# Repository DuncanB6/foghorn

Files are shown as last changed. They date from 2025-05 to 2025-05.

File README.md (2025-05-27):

# Foghorn

<p align="left">
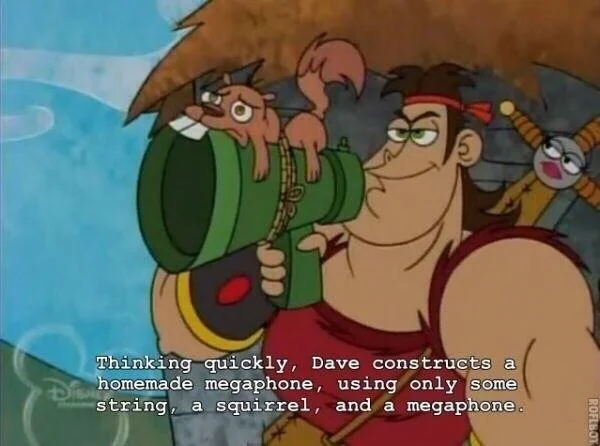
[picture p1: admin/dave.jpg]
  
</p>

A short range portable FM transmitter.

---

## Table of Contents

- [Overview](#overview)
- [Project Structure](#project-structure)
- [Hardware](#hardware)
- [Firmware](#firmware)

---

## Overview

This is an FM transmitter that a user can use to broadcast their voice or audio from an AUX port on the FM band at short ranges. As an audio source, it uses either an onboard microphone or the external AUX port. The user can transmit their voice much like a walkie talkie, and can play music if they want. The transmitter is tunable to any FM band frequency using buttons.

<p align="left">
  Foghorn Project Banner
</p>

The project was originally named Foghorn because I had imagined it as a megaphone. I though this would allow for some interesting antenna design, and also be funny. However, after realizing that the antenna didn't matter too much, I fell to the tempation of making it smaller, and so a radio design was born.

Foghorn is built on a series of development boards. An ESP32 board provides the computing, which is connected to an electret microphone, LCD screen, FM transmitter, and the buttons and switches needed to run the device. The whole thing is powered by a lithium ion battery, rechargable using a battery board. Firmware is written using ESP-IDF.

<p align="left">
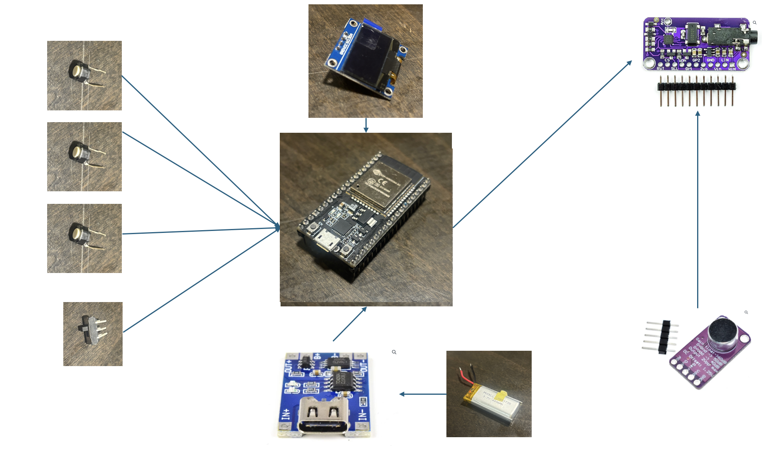
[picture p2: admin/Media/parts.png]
  
</p>

---

## Project Structure

This repository contains everything involved with this project. Some of the main folders are as follows.

- admin: Administrative stuff, such as a log, BoM, pictures, etc.
- arduino: Code used with an Arduino Uno to test out the FM transmitter.
- main: Firmware for the ESP32, used in the final version.
- stls: STL files used for mechanical parts (3D printed).

## Hardware

### Electronics

This device consists of several development boards and other odd electronics. A sketch of the system is shown below.

<p align="left">
  Foghorn Project Banner
</p>

All parts are wired together using 26AWG wire and heat shrink.

#### Battery Board (BB)

The battery board is a board that allows for the charging of my lithium ion battery. I don't know what kind of battery it is (3.7V 400mAh) cause I just had it lying around. The battery board provides 3.3V and ground terminals for the entire system. The BB can be found here: https://www.universal-solder.ca/product/3-7v-lithium-charger-usb-c-1a-charge-3a-output-protection-usb-c/

#### FM transmitter

The FM transmitter is connected to the ESP32 via I2C and the microphone using a single line. It transmits at a short range on the FM band. An approximately 20cm wire antenna extends out from this board. You can find it here: https://www.universal-solder.ca/product/si4713-fm-stereo-transmitter-module-with-rds/

#### Microphone

The microphone is an electret microphone board with adjustable gain. I have it set to the lowest setting (40dB) right now, which works fine. Its analog output is connected to the analog input of the FM transmitter. Find it here: https://www.universal-solder.ca/product/hifi-microphone-module-with-max9814-amplifier/

#### LCD

THe LCD is a 4056 powered 128x64 I2C LCD. It is connected on the I2C lines to the ESP32 board. This provides a 0.97" monochrome display to display the frequency. I don't have a link cause it was just lying around.

#### ESP32

The ESP is connected to all of the peripherals. Also just had this lying around, so no link for you. It's a pretty standard ESP dev board though.

#### IO

There are 3 buttons and one switch. The switch is on the 3.3V line between the battery board and the rest of the system. THe push to talk button is on the analog audio line between the FM transmitter and the microphone. The up and down frequency buttons are connected to two ESP32 GPIO inputs.

### Mechanical

Most parts are 3D printed using my Prusa Mk3S+ printer. The case is made from brown ASA, the buttons from green ABS, and the antenna from flexible TPU. Parts are fastened together using M2.5 screws and heat inserts. The buttons and switch are glued in.

<p align="left">
  Foghorn Project Banner
</p>

Parts were designed in Onshape. Note that M2.5 screws was a bad choice, since these take up more space than necessary and don't fit in the microphone or LCD mounting holes (although for the LCD I made it happen).

<p align="left">
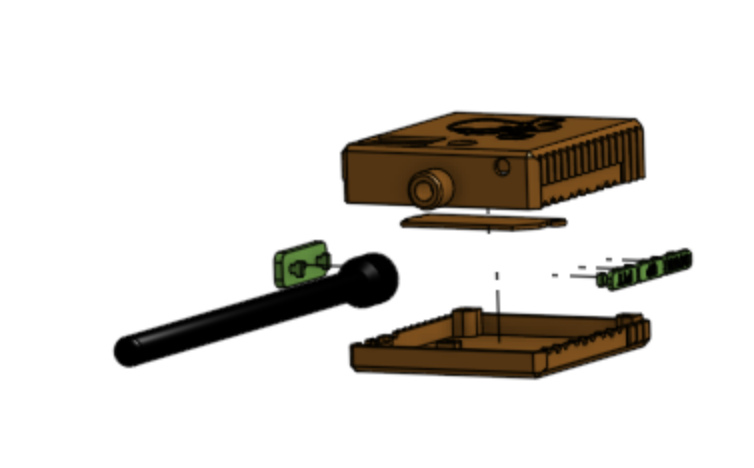
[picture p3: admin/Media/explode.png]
  
</p>

## Firmware

The current firmware is in the "main" folder. This firmware is responsible for interacting with all of the peripherals. All processing happens in a single task. The initialization flow is as follows.

1. Initialize I2C (LCD and FM transmitter)
2. Initialize GPIO
3. Initialize LCD
4. Initialize FM transmitter (begin transmitting)
5. Display initial frequency on LCD

Once initialization is complete, we enter the main loop. If the frequency up button is pressed, the frequency is increased by 0.2 MHz and the FM transmitter is tuned to match. The new frequency is displayed. I'll let your imagination fill in what happens when the frequency down button is pressed.

In the background, the LCD screen is constantly updated. Otherwise, the only task the ESP32 performs is monitoring the frequency up and frequency down buttons.

Code is fairly sparsly commented, and has undergone some pretty major shifts, so I make no claims to this being particularily robust or clean work.

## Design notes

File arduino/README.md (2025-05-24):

# foghorn-arduino
Arduino firmware for testing and development towards the Foghorn project

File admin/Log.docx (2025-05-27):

Foghorn Log:

Apr 4:

- Did some initial research, I have some components that seem promising
  - I need to finish component selection before I can order
- Do I need an amplifier?
  - If there are relatively easy, cheap options, I’ll do this
- I want input from either ESP32 or microphone, is it easier to do this before or after the DAC?
  - How does I2S work? Can I share lines, and will having 3 devices on the line cause problems for the unused device?
  - It seems like I probably want to do this before DAC if possible, to avoid issues with analog levels/amplification

Apr 7:

- I ended up buying some parts, the Adafruit FM transmitter, a DAC, and a microphone
  - ESP32 can handle I2S audio, but I can’t share a line because it would have to be master and slave at once (only one channel)
- No amplifier at the moment, I may have to look at amplifying options later, but that will be a stretch goal
- Going to get through finals and wait for parts to arrive, then we roll!

May 8:

- Parts are all here, and I’m free from school, time to get to work
- First step is reviewing hardware
  - I’ll try out just the FM transmitter first with an audio source
- Oopsie, first hardware oversight, I’ll need an aux cable to test this out
  - Will buy
- Initial setup:
  - Arduino UNO on breadboard
  - Wires soldered to relevant FM transmitter pins
  - Phone connected to aux input
- I have all hardware set up
- When running the example code, I seem to have an issue with the I2C connecting
  - Make sure connections are all good
    - Seems all good, but reset and ground are connected when powered, why?
  - Try authentic Arduino
    - Same result
  - Investigate voltages
    - I2C pins seem to be high
    - Reset is 3.3V, why?
  - Very strange that reset (pin 12) and GND are both connected and separated by 3.3V when the thing’s running
  - Review code
    - Seems like a normal connection, I might revisit this, but ok for now
  - Pullup resistors
    - Added 10k resistors, no luck
- Fixed!
  - Connecting the reset pin and ground seems to solve the problem, I’ll have to figure out a software solution to this
    - Added a manual reset with the reset pin
- Radio works well
  - Very clear
  - 10m range with no problems
  - 50m absolute range
- May play with antenna a bit
- Done for today, next step is to integrate more components!

May 10:

- Damn it, I drained a pair of AAAs by leaving the radio receiver on
  - Gonna make it a habit to take batteries out
- Next steps:
  - Test to see if the device works without pullup resistors
  - Figure out why it seems to work intermittently
  - Figure out how it works
  - Set up github project (?)
  - Begin porting to ESP32
- Works fine without pullups, although same issues with inconsistency
- Ok, I have ideas for a solution to fix consistency, but first let’s set up the git so I don’t mess this up
- The antenna capacitance could be an issue
  - I’ve shortened the antenna to about a foot, still same behaviour
  - Tried a few different frequencies, no change
  - Tried adding a delay after reset, this may have improved things slightly, but problem is not solved
  - Aha, adding this delay after the begin function (I2C init?) solves the problem
    - This was because of a ramp-up time that the crystal oscillator needs, which explains the close but not quite freqs I was getting sometimes

May 11:

- Focus for today is transferring to ESP32 hardware
- First step is to see if I can get it working using raw I2C commands, that way I can transfer easily without worrying as much about hardware
  - Will start this by reading the FM transmitter programming datasheet
- Looks like I might not need a DAC after all, it has digital audio input options including I2S
- Wait a second, what if I can just use the existing library?
  - I have decided to not do that
  - Although possible, it’s going to be tricky to port, and I’d rather deal with low level I2C command sending trouble than library trouble
- Switched to using VS Code and PlatformIO for this
  - Open serial monitor using command palette
- Yay, got it set up so that I can power it up using a few of my own commands (but mostly still library)
- I think this serves as a good proof of concept, I’m going to make the leap to ESP32
- First step is setting up the build environment, this will require a lot of transfer from the old code
- Build env set up
- Added I2C and GPIO init functions
- Next step is to begin the long and arduous process of initializing using I2C

May 13:

- I’ve just tried getting the part number off the FM transmitter with I2C and Arduino, this will be a good first step for ESP32
- Now to do the hardware wiring
- No FUCKING way it worked first try
- Now to reorganize/format my code so that it’s a bit cleaner before moving forwards
- Alright, on to the grindy part of adding all the commands I want
- We’re balling
  - FM transmission working from ESP32
- Now just gonna chuck it into a task

May 14:

- Sike, I2C error
  - May be hardware, will investigate
  - Fixed, was just a mistake with passing i2c handle
- Decided not to put init in task for now, since it only needs to run once
- Going to look into I2S, ideally I’d like to try I2S transmission from ESP to FM without involving mic first
- Sike, the mic is not I2S, that’s actually nice
- Means I’ll do ADC on ESP32, but always output I2S
- Sike, I can’t use digital with the FM radio, must transmit to DAC first
  - Just took me quite a while to figure out stuff I already knew a month ago
- Note that setting the mute pin high on the DAC mutes the output, this could be a good way to implement push-to-talk
- Just wired up DAC, now computer doesn’t recognize ESP, very concerning, will debug
  - Cause by a solder bridge
  - Yikes, looks like this put the esp into bootloader mode
  - Hmm, seems like the issue is that my new firmware was so aids that it bricked the MCU
- Sequence to unbrick:
  - While holding boot, press reset (GPIO9 floating)
  - Flash the code (will fail)
  - While holding boot, press reset (GPIO9 pulled to high)
  - Flash code
- So it seems pins 12 and 13 are used for the JTAG interface, this is almost certainly causing the issue
- Will resolder to pins 19, 20
- Ok, it kinda works now, but there’s some kinda issue that causes distortion
  - In any case, enough for today

May 15:

- I’m not going to bother fixing the I2S sine wave, since it way be a problem with the wave, not the I2S
- Instead, let’s get the microphone set up
  - After soldering microphone, I get an issue with too much power, gonna try restarting mac
- Beginning to think I’ve fried my esp32, I’m gonna start removing connections, if it is broken I’ll have to do this anyways
- All desoldered and same result
  - I hate this board
- Since board is broken, I need to reevaluate my hardware
- Ok I’m gonna pivot and use ESP32 with SDD1306 LCD display
  - I have two ESP32s
- Gonna put everything together on a breadboard
- Soldering time

May 16:

- Got the FM working and maybe the DAC, but gonna try mic first
- First I’ll connect and just read a stream to see what’s up
  - Mic seems to be reactive at least, now to convert to I2S
- Not sure what the best way of passing data is
- Set up a queue, but should get DAQ done with a timer for consistent sampling freq

May 19:

- First step is to get acquisition on a timer for consistency
- Then I’ll work on using that data (converting and sending on I2S)
- Ok, DAQ is on timer, using 44.1kHz for now, may change
- Now to set up my receiving task that sends to I2S
  - Data consumption done, now just need to send
- I get audio from the DAC, but it’s incomprehensible at low sample rates and my queue overflows at high sample rates
- I have a feeling high data rates are gonna pose some issues

May 20:

- Round two!
  - Got to figure out high freq sampling
  - First, let’s determine exactly who is blocking
- Looks like I can’t sample the ADC in the kHz range (or at least 16kHz)
- What if I connected the mic’s analog out directly to the FM transmitter?
  - Would mean I’d need to control the FM transmitter to control output
  - May run into the same problem later with I2S comms
    - But Bluetooth (the only thing that needs I2S) is a stretch goal anyways
- Fuck yeah baby she’s going!
- Ok so massive simplification
  - DAC is completely dropped
  - Mic output goes directly into FM
- Next steps:
  - Figure out how to turn FM on and off
- I think it’s acceptable if the mic has a button on the output line
  - Means the radio will hear silence even when voice is not being transmitted
  - But this is ok, simplifies things, and may even be a feature
- Wow, now I just need to sort out tuning and the power cycle!
  - Huge progress by cutting fat
- I2S should be kept in, as it could be implemented later
  - Will be saved in a commit
  - Will have to remember to wire it up for I2S (or Bluetooth output of some sort)
- I should try the other gain settings on the mic before wiring everything up
  - Tried high gain, I prefer just regular, it sounds fine
- Got FM tuning IO going, as well as push to talk
- Now for the most feared part, the screen
- I likely have the following screen:
  - SSD1306 controller
  - 128x64 size screen
- Ok, after a lot of poking around, I have a demo going
- Now I just need to integrate this into my main project
- Raaahhhhhhhhhhhhh
  - Got the frequency display working
  - May see if I can get an indicator going for the voice
  - That may be tricky given the way I’ve implemented it (button on line)
- Should add some safeties for the FM limits
- Wow, I think I’m pretty much done!
- Should test plugging a phone on while the mic is running
  - No problem, phone audio overwhelms mic audio
- Let’s check out how the battery board needs to work, then I’ll start CAD!
  - Seems it doesn’t really talk with smart chargers like my laptop or its charger
  - Does seem to work otherwise
- CAD time!
- I’m gonna need some kinda glue to hold all my parts in place

May 21:

- First test print done, gonna disassemble board to test parts
- Rev two is printing now, made some good changes, this rev is technically fully functional
  - Although it probably will have mistakes
  - And is unpolished
- Print is 80% done, seems something got messed up on 2 layers
  - Maybe filament got stuck, not sure
  - Should still be enough to try out the next rev

May 22:

- After some adjustments, I’m now printing what I hope to be the final rev
- Also have ordered some stuff for assembly, which I’ll likely do Saturday
- All looking good, now we just wait for prints and parts
- Docs are gonna be a bit of a pain, but I can do that in my own time later

May 23:

- Only part left to print in antenna
- TPU is annoying, the height of it causes a lot of wobbling, and supports are unusable
- Gonna try printing real slow
- All parts printed, they look pretty good
- Now to wait for parts to arrive (today) and we can start the final build

May 25:

- I’ve made it most of the way through the build
- Unfortunately, I need to order parts
- The LCD screen seems to be broken, which is likely given what I was doing to it, and I’ve run out of leaded solder (and soon unleaded)
- New parts are ordered, but build is on hold till they arrive
- Final steps:
  - Replace LCD
  - Test LCD
  - Glue in buttons and switch
  - Wire switch
  - Wire button positive leads
  - Test system
  - Done!

May 26:

- Just replaced the LCD but am having the same issue
- Will look into a few things, but if this thing came broken or was immediately broken by soldering I’ll piss myself
- To check:
  - Getting 3V3 power?
    - Yes, but maybe adding a cap would help?
  - Pins are correct (in firmware)?
    - Fuuuuuuuuuuuuck
- Ok so I really should have checked that before getting a new screen, old one is likely not broken
  - Damn it
- New screen is not quite the right size, but it’s close enough and also blue so I’ll keep it
  - Also was planning on gluing the screen anyways cause the mounts are bad
  - The holes are 2mm (my screws are 2.5mm)
- All installed, and to nobody’s surprise it works
- Glued parts, just waiting for them to dry now
- Call me god king Duncan

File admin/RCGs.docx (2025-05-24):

Description:

The Foghorn should be a handheld electronic device that receives a user’s voice using a microphone and broadcasts it on an FM band. It should be tunable so that the user can choose the frequency of broadcast.

The user should see the current frequency displayed on the device and be able to adjust it with physical controls. The users voice should only be broadcast when the user applies a physical control (e.g. button, trigger).

The device should be able to broadcast a signal such that a nearby FM radio can receive that signal. The FM radio user should be able to discern what the Foghorn user is saying.

The device should be battery powered and rechargeable. It should be able to be switched off when not in use. The entire package should fit within a microwave.

Use:

The user turns on the device using a switch. After a short boot time, the device is ready for use. The user can adjust buttons to adjust the frequency, which is displayed on a small screen on the side of the device. Next, the user can depress a trigger or button and begin speaking. When the button is released, live transmission stops. The user can switch off the device using the power switch.

Requirements:

- Users voice must be comprehensible on an FM radio up to 10 meters.
  - Device will be used 10 meters from a radio. FM radio input will be recorded.
- Output frequency must be able to consistently target a single FM frequency within 0.2MHz.
  - 5 different frequencies will be checked on the FM band. Device should transmit at the target frequency but be inaudible at adjacent (+/- 0.2MHz) frequencies.
- Battery should last for up to 30 minutes of continuous use.
  - Device will be powered on and set to broadcast at medium power for 30 minutes.
- User must be able to tune frequency across the FM band.
  - Check minimum and maximum FM frequencies using an FM radio.

Constraints:

- Must fit within a handheld (toaster or smaller) package.
- Must transmit quietly enough to avoid annoying or alerting the public in a radius larger than 100 meters.
- Total parts cost must not exceed $300.

Goals:

- Allow audio input to be played from device using a wireless connection with a phone.
- Allow for tunable power for longer or shorter ranges.

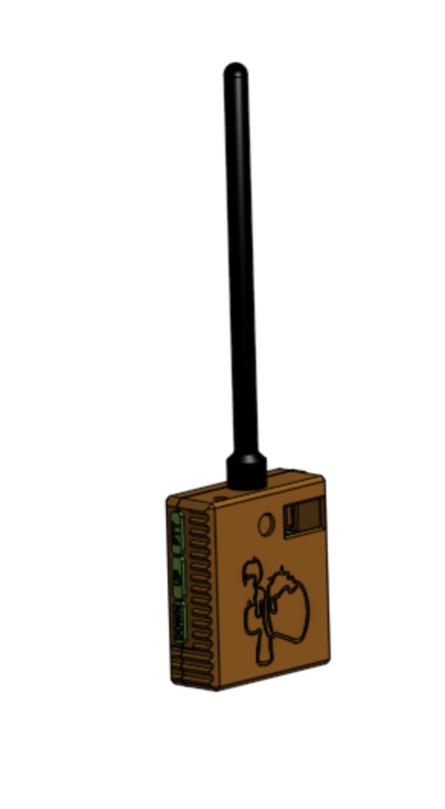
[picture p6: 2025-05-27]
admin/Media/complete.png

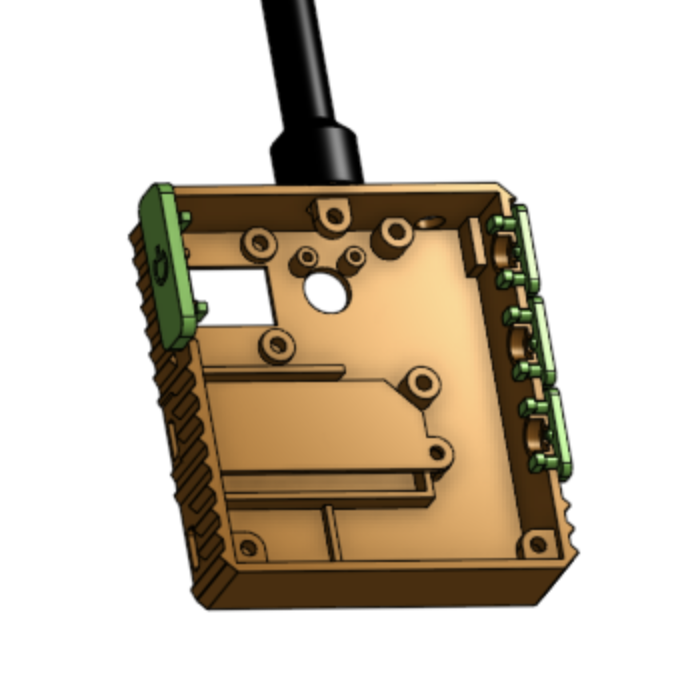
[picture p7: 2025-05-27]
admin/Media/case.png

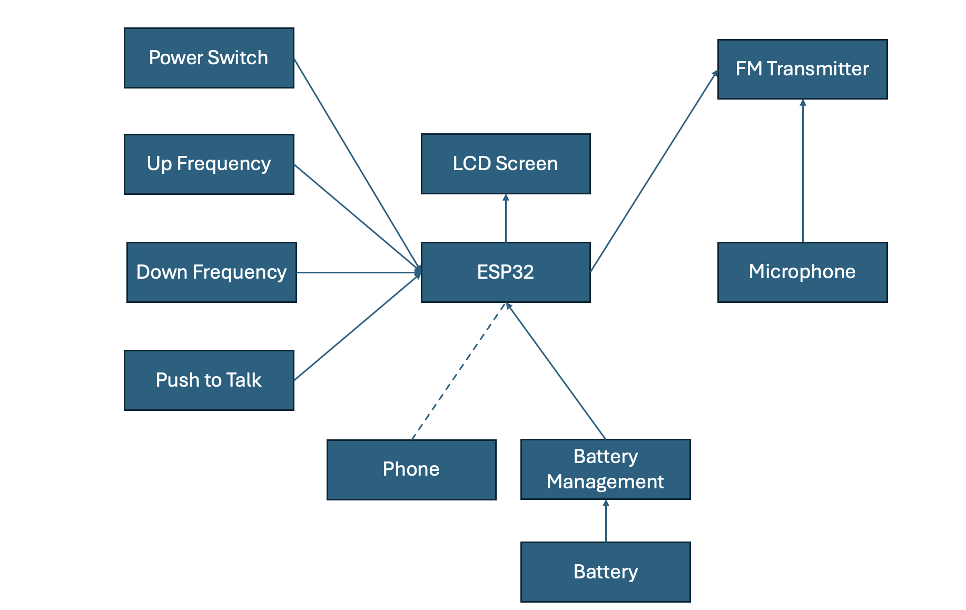
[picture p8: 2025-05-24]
admin/Media/block.png

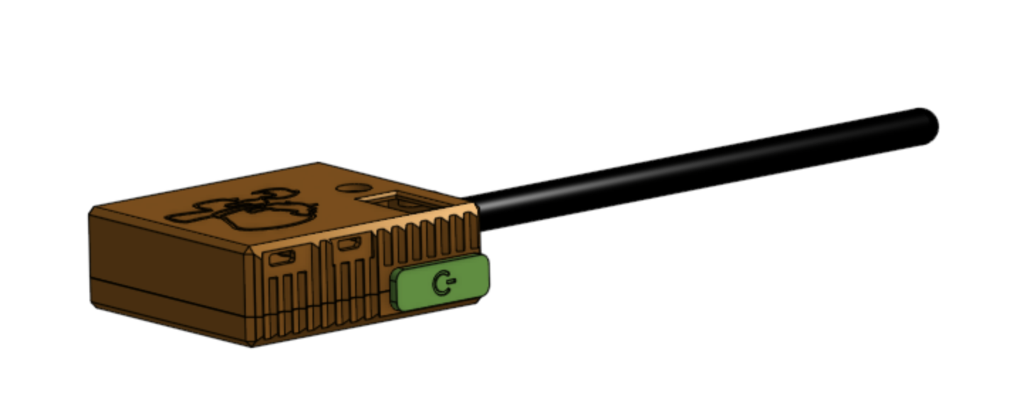
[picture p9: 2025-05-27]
admin/Media/side.png

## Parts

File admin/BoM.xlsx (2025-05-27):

Item | Cost (CAD) | Link | Running Total: | 127.0302
Adafruit FM Transmitter | 13.9 | https://www.adafruit.com/product/1958
Microphone Module | 3.95 | https://www.adafruit.com/product/1713
Battery Charger | 1.49 | https://www.universal-solder.ca/product/3-7v-lithium-charger-usb-c-1a-charge-3a-output-protection-usb-c/
Universal Solder Shipping | 4.9 | NA
Universal Solder Tax | 2.32 | NA
Adafruit I2S DAC | 10.147 | https://www.adafruit.com/product/3678
Adafruit Shipping | 26.1632 | NA
ESP32 C6 | 31.35 | https://www.amazon.ca/ESP32-C6-Microcontroller-1-47inch-Colorful-Applications/dp/B0DHVQYFGM
AUX Cable | 12 | NA
Wire, Glue, and Screws (Amazon) | 0.37 | NA
Replacement Screen and Solder | 20.44 | NA

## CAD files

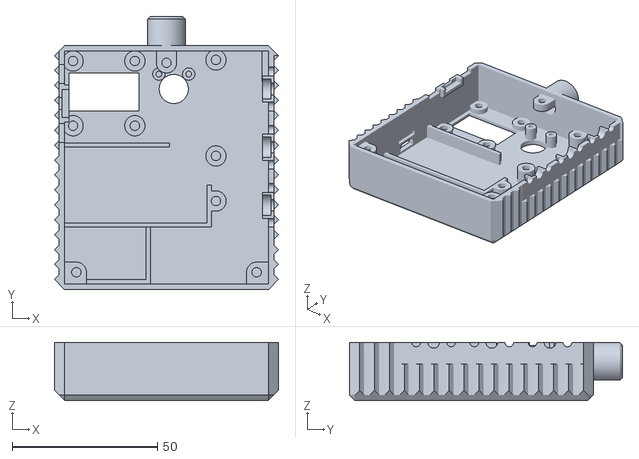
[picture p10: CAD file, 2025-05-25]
stls/Front - Part 1.stl
77.0 x 94.0 x 20.0

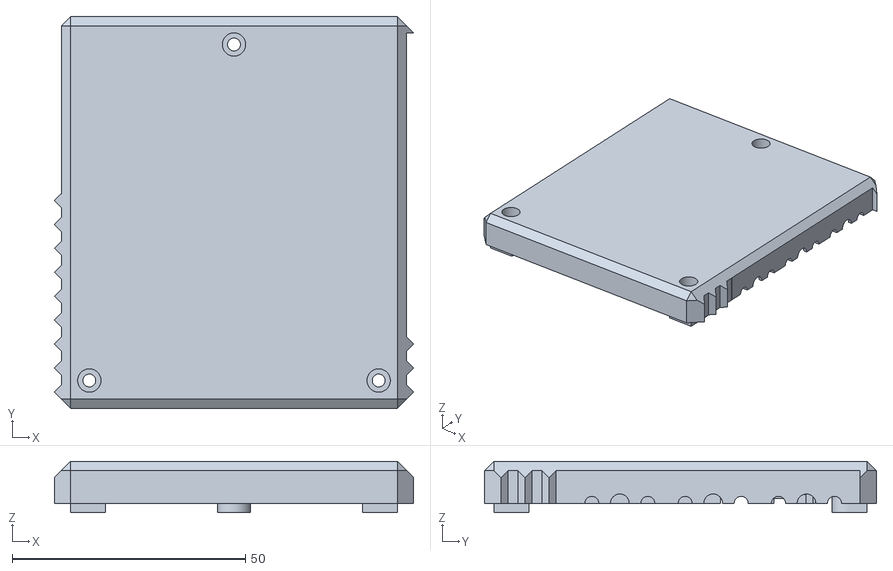
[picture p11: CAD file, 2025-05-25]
stls/Front - Part 2.stl
77.0 x 84.0 x 11.0

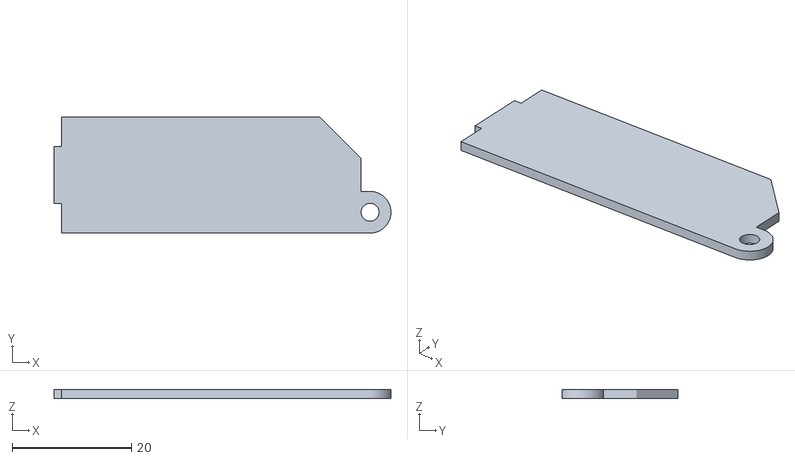
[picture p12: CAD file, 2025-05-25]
stls/ESP Cover - Part 1.stl
56.5 x 19.5 x 1.50

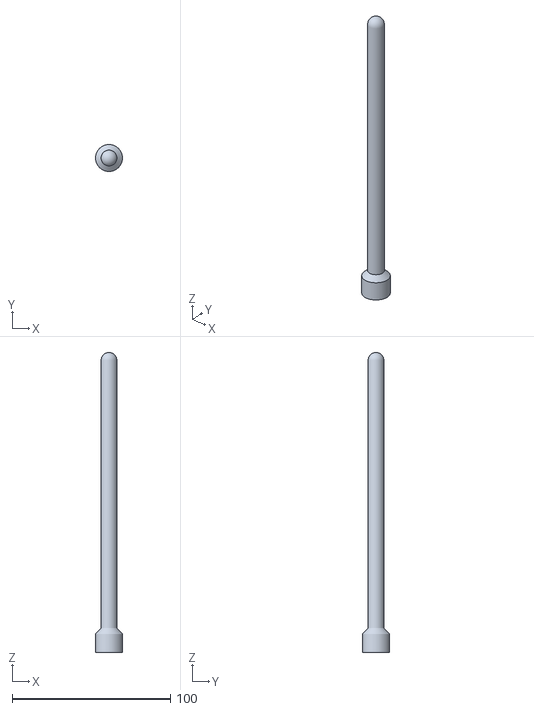
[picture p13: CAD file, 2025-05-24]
stls/Antenna.stl
17.0 x 17.0 x 189.5

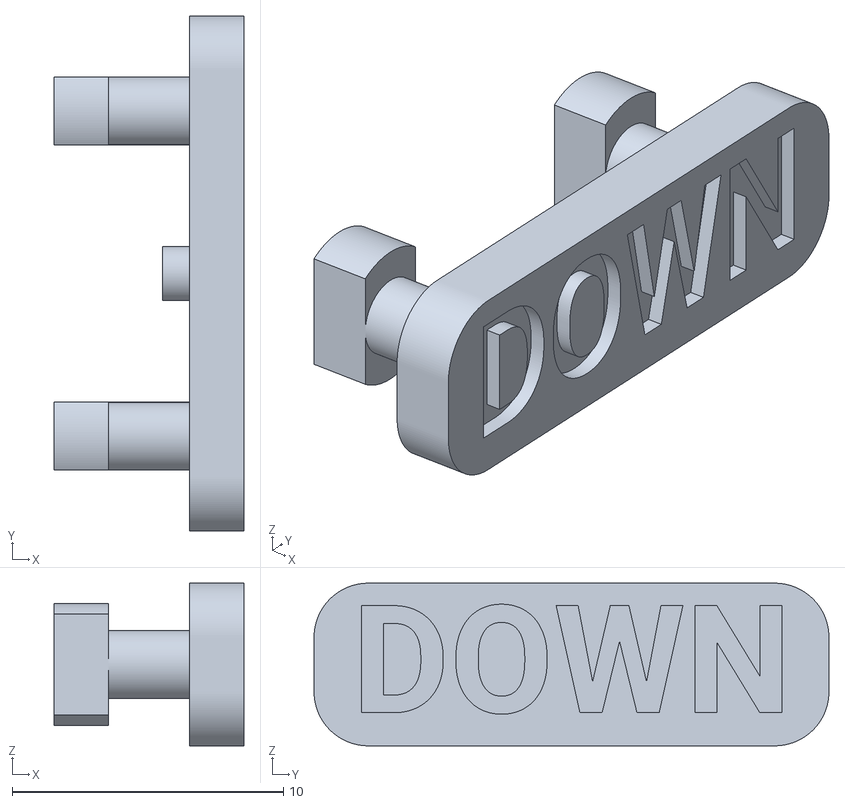
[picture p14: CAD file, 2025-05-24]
stls/Down Button - Part 1.stl
7.00 x 19.0 x 6.00

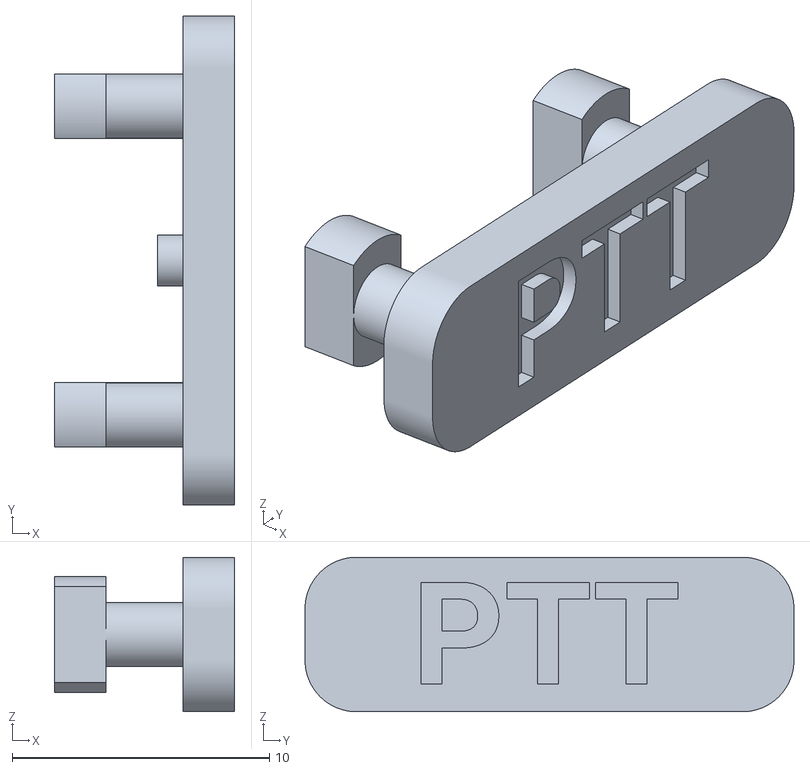
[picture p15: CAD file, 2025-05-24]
stls/PTT Button - Part 1.stl
7.00 x 19.0 x 6.00

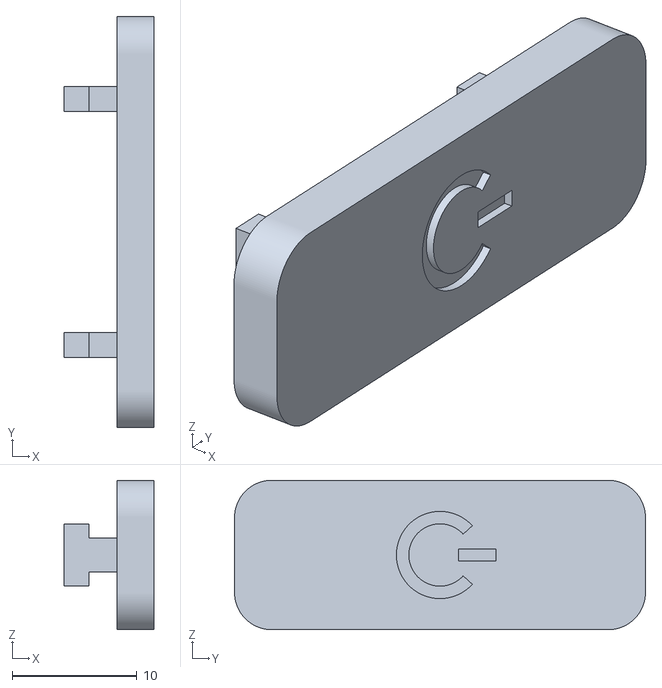
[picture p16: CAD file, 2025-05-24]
stls/Switch - Part 1.stl
7.25 x 33.0 x 12.0

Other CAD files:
stls/Up Button - Part 1.stl

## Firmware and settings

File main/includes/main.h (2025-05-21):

#ifndef _MAIN_H
#define _MAIN_H

#include <stdio.h>
#include <math.h>
#include <string.h>

#include "driver/i2c_master.h"
#include "driver/gpio.h"
#include "freertos/FreeRTOS.h"
#include "freertos/task.h"
#include "freertos/queue.h"
#include "esp_log.h"
#include "ssd1306.h"
#include "font8x8_basic.h"

extern QueueHandle_t data_queue;

extern i2c_master_dev_handle_t i2c_dev;
extern SSD1306_t lcd_dev;

void init_i2c_0(i2c_master_dev_handle_t* i2c_dev);
void init_gpio(void);


// I2C specific
#define DEFAULT_SCL_SPEED_IN_HZ   (400000)          // 500KHz
#define DEFAULT_GLITCH_IGNORE_CNT (7)
#define DEFAULT_XFER_TIMEOUT_MS   (-1)
#define DEFAULT_I2C_PORT          (0)
#define DEFAULT_I2C_INTR_PRIORITY (0)
#define SI4713_I2C_ADDR           (0x63)            // for SI4713 FM transmitter

#define SI4713_RESET_PIN          GPIO_NUM_23       // for SI4713 FM transmitter
#define TUNE_UP_PIN               GPIO_NUM_32
#define TUNE_DOWN_PIN             GPIO_NUM_33

extern int fm_frequency;


#endif

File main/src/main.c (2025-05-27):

#include "main.h"
#include "fm_transmitter.h"
#include "lcd_screen.h"


QueueHandle_t data_queue;

i2c_master_dev_handle_t i2c_dev;
SSD1306_t lcd_dev;


void app_main(void) {

    printf("Beginning application...\n");

    init_i2c_0(&i2c_dev);
    init_i2c_1(&lcd_dev, GPIO_NUM_26, GPIO_NUM_25, GPIO_NUM_0);
    init_gpio();
    ssd1306_init(&lcd_dev, 128, 64);

    vTaskDelay(pdMS_TO_TICKS(100));

    init_fm(&i2c_dev);

    display_freq();

    while(1)
    {
        if (gpio_get_level(TUNE_UP_PIN)) {
            fm_frequency += 20;
            if (fm_frequency > 10810) {
                fm_frequency = 8750;
            }

            tune_fm_freq(&i2c_dev, fm_frequency);
            display_freq();
            
            vTaskDelay(pdMS_TO_TICKS(100)); 
        }
        if (gpio_get_level(TUNE_DOWN_PIN)) {
            fm_frequency -= 20;
            if (fm_frequency < 8750) {
                fm_frequency = 10810;
            }

            tune_fm_freq(&i2c_dev, fm_frequency);
            display_freq();

            vTaskDelay(pdMS_TO_TICKS(100)); 
        }
        vTaskDelay(pdMS_TO_TICKS(10)); 
    }  

    printf("Exiting application...\n");

    return;
}


void init_i2c_0(i2c_master_dev_handle_t* i2c_dev) {

    printf("Initializing FM I2C...\n");

    i2c_master_bus_config_t i2c_mst_config = {
        .clk_source                      = I2C_CLK_SRC_DEFAULT,
        .i2c_port                        = DEFAULT_I2C_PORT,
        .sda_io_num                      = GPIO_NUM_21,
        .scl_io_num                      = GPIO_NUM_22,
        .glitch_ignore_cnt               = DEFAULT_GLITCH_IGNORE_CNT,
        .flags.enable_internal_pullup    = true,
    };
    i2c_master_bus_handle_t bus_handle;
    ESP_ERROR_CHECK(i2c_new_master_bus(&i2c_mst_config, &bus_handle));

    i2c_device_config_t dev_cfg = {
        .dev_addr_length = I2C_ADDR_BIT_LEN_7,
        .device_address = SI4713_I2C_ADDR,
        .scl_speed_hz = DEFAULT_SCL_SPEED_IN_HZ,
    };
    ESP_ERROR_CHECK(i2c_master_bus_add_device(bus_handle, &dev_cfg, i2c_dev));

    printf("Initialized FM I2C\n");

    return;
}


void init_gpio(void) {

    printf("Initializing GPIO...\n");

    uint64_t pin_bitMask = 0;
    pin_bitMask |= (1ULL << SI4713_RESET_PIN); // reset for FM transmitter

    gpio_config_t io_conf = {
        .pin_bit_mask = pin_bitMask, 
        .mode = GPIO_MODE_OUTPUT,              
        .pull_up_en = GPIO_PULLUP_DISABLE,     
        .pull_down_en = GPIO_PULLDOWN_DISABLE, 
        .intr_type = GPIO_INTR_DISABLE         
    };
    gpio_config(&io_conf);

    // Configure GPIO32 and GPIO33 as inputs
    uint64_t input_pin_mask = (1ULL << TUNE_UP_PIN) | (1ULL << TUNE_DOWN_PIN);

    gpio_config_t io_conf_input = {
        .pin_bit_mask = input_pin_mask,
        .mode = GPIO_MODE_INPUT,
        .pull_up_en = GPIO_PULLUP_DISABLE,
        .pull_down_en = GPIO_PULLDOWN_ENABLE,
        .intr_type = GPIO_INTR_DISABLE
    };
    gpio_config(&io_conf_input);

    printf("Initialized GPIO\n");

    return;
}

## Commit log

2025-05-12 i2c init (untested)
2025-05-13 initializes fm using i2c and gets rev
2025-05-13 i2c command clean
2025-05-13 powerup and rev functions
2025-05-13 able to tune to correct frequency
    [fm_transmitter.c]
2025-05-15 changed target to esp32, does not work
    [main.c, main.h]
2025-05-15 fm trans works again (and i2c)
2025-05-19 daq on timer
2025-05-21 removed prints
2025-05-21 freq adjusts constantly by holding button
2025-05-24 added admin and arduino, unifying repos
    [Antenna.stl, BoM.xlsx, Down Button - Part 1.stl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]
2025-05-24 moved stls
    [Antenna.stl, Down Button - Part 1.stl, ESP Cover - Part 1.stl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]
2025-05-25 readme and new version of stls
    [ESP Cover - Part 1.stl, Front - Part 1.stl, Front - Part 2.stl]
2025-05-25 changed init prints
2025-05-27 done readme, final admin changes
    [BoM.xlsx]
